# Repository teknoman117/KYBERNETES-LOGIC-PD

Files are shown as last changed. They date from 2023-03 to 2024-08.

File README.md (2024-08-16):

# Kybernetes 2 Logic Power Distribution Board

Power Distribution board for Kybernetes 2. Provides current monitoring and battery protection for a 3 cell LiPo battery and provides 5V via four USB-C ports.

Current monitoring IC is the INA219B and the switching regulator board is the Pololu D15V70F5S3. A open collector output is also provided to indicate low battery voltage.

Schematic

### Assembled
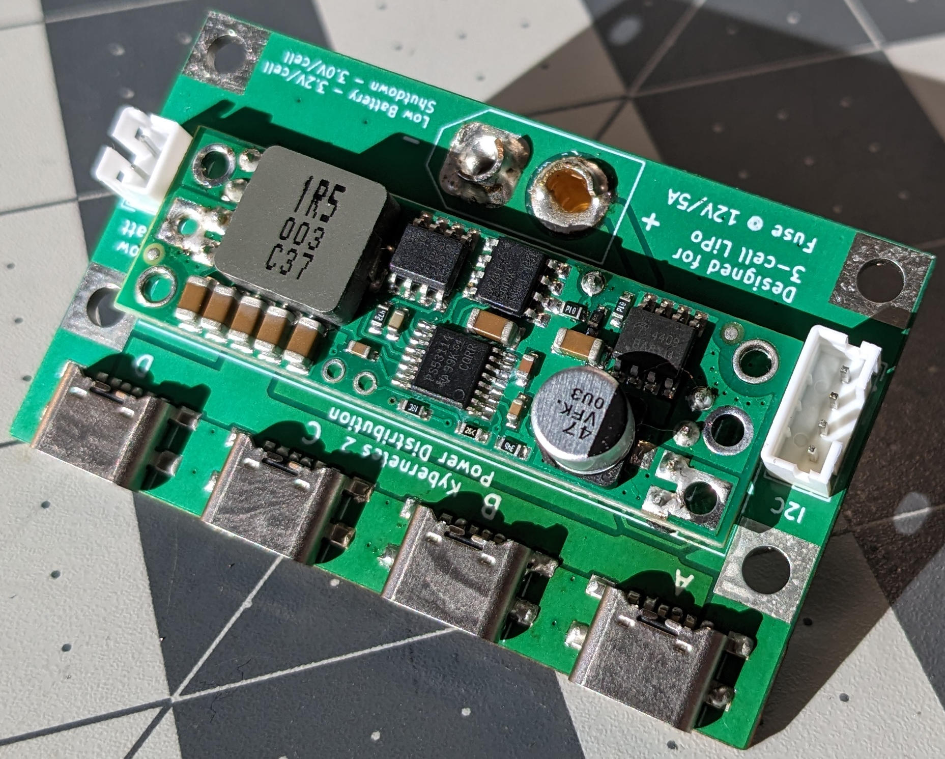
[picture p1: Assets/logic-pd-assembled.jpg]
Assembled


### Switching Regulator Removed
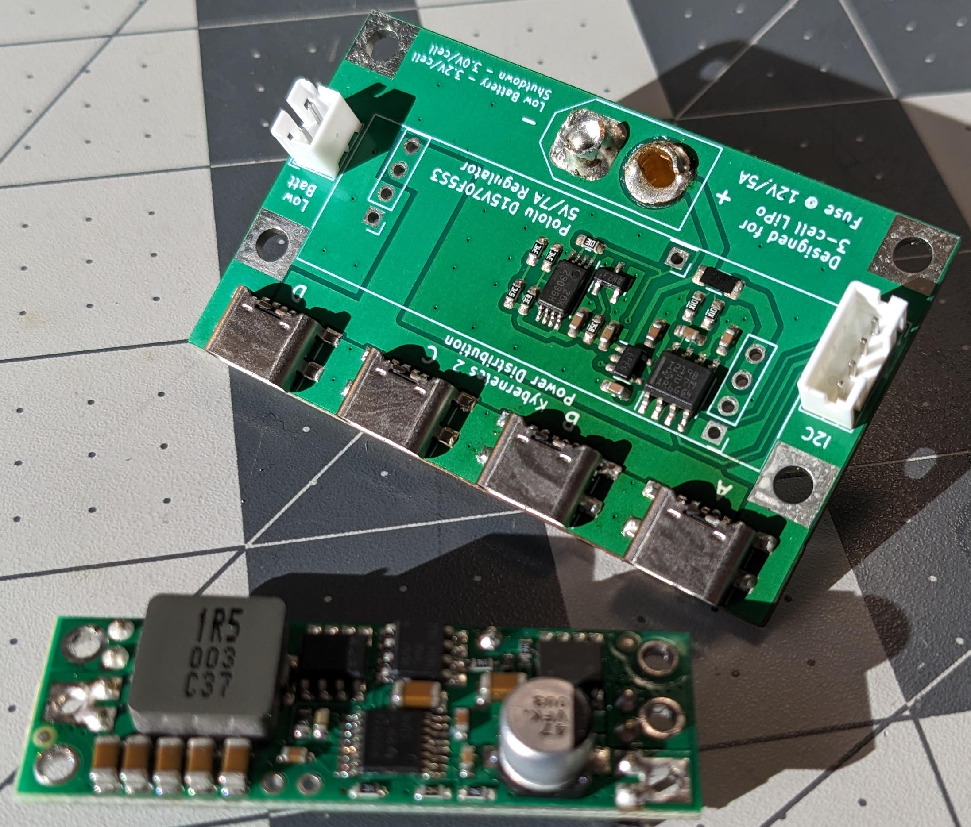
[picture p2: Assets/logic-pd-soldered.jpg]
Soldered


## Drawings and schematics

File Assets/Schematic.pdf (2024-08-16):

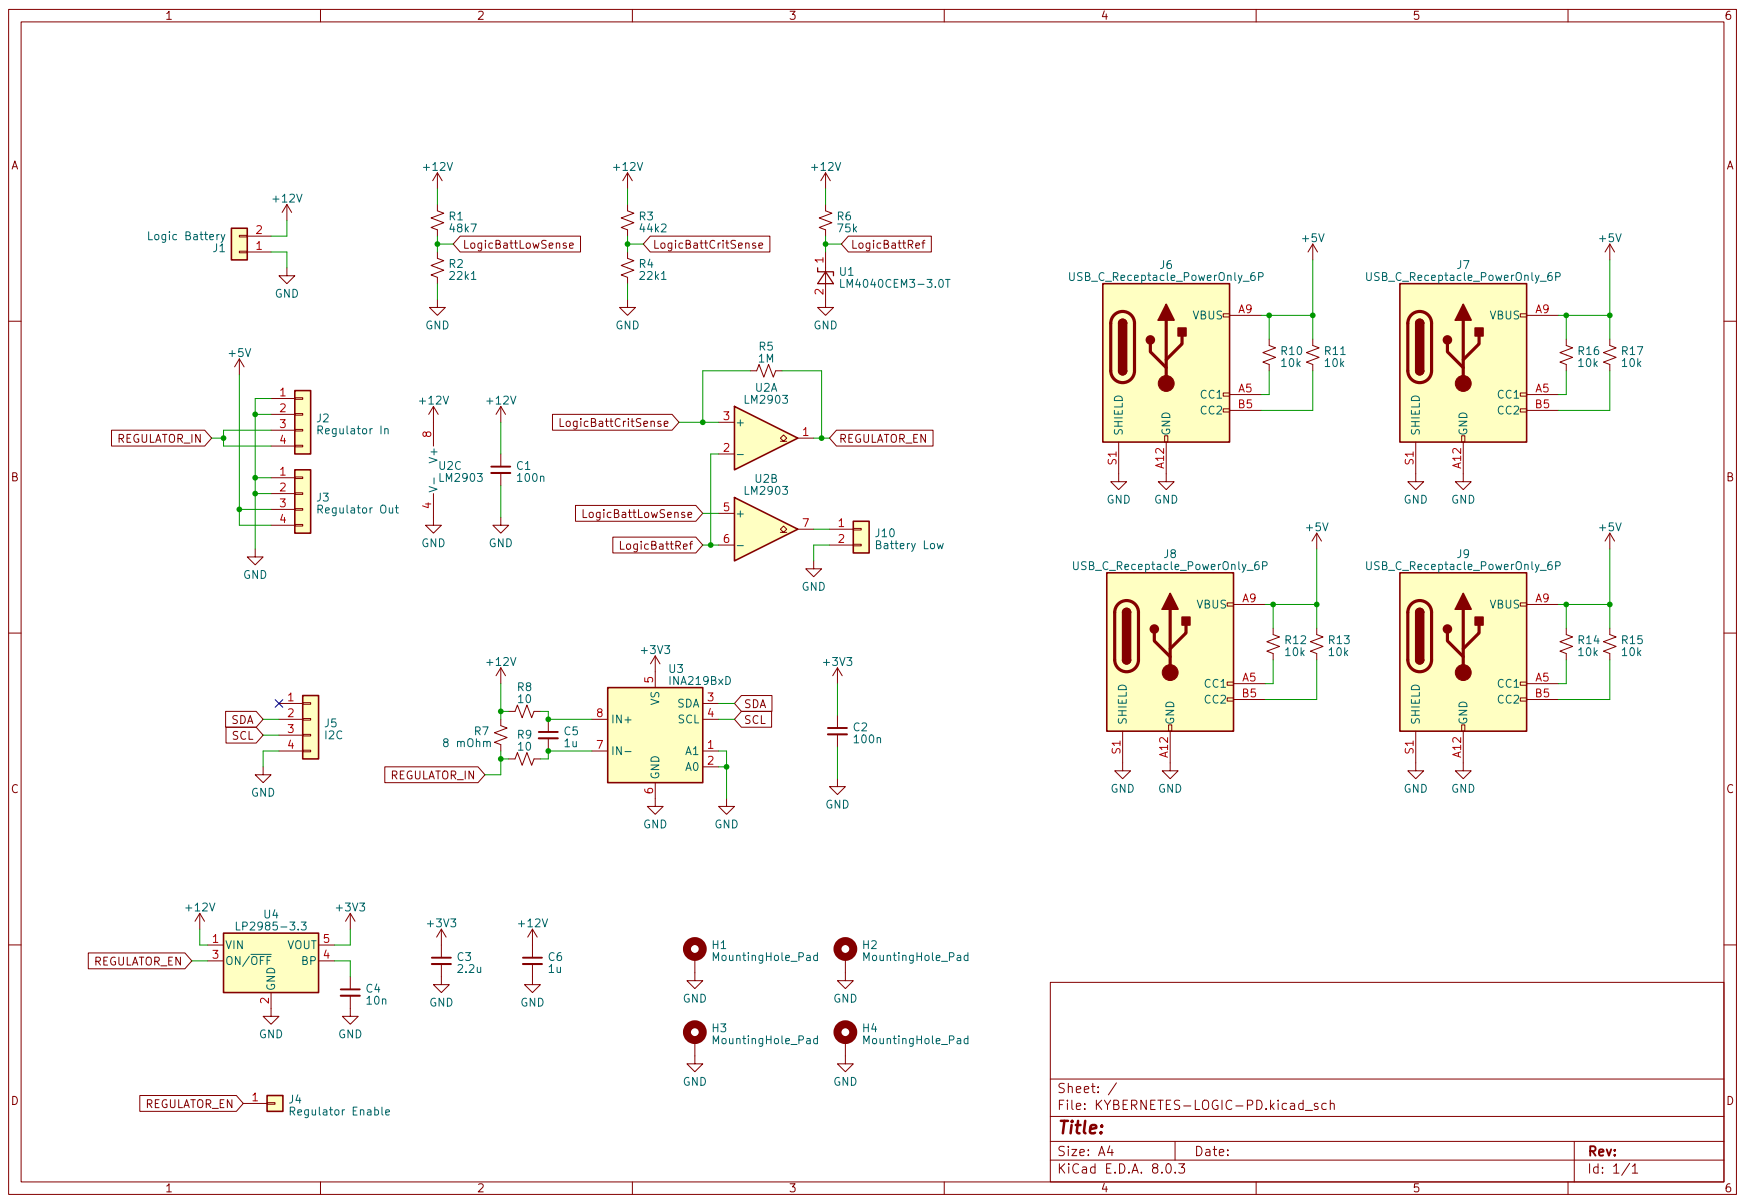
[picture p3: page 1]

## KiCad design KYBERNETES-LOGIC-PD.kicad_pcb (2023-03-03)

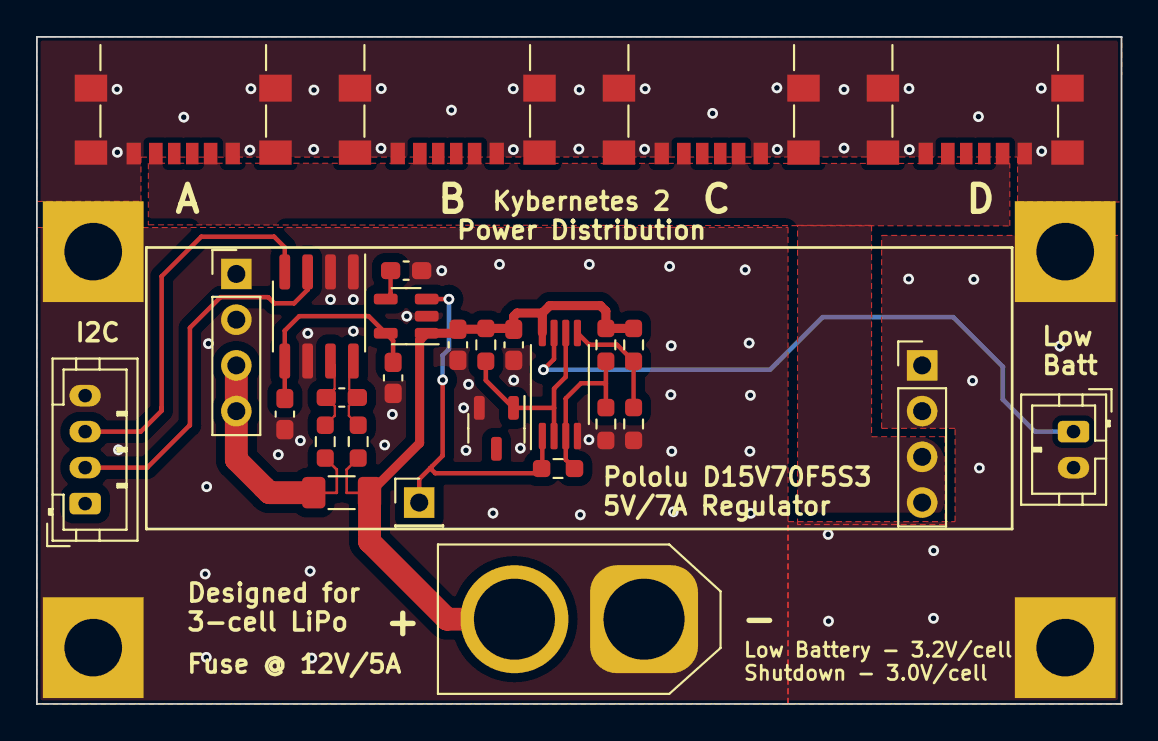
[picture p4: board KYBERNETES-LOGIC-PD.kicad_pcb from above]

Board: 2 copper layers, 60.3 x 37.1 mm, 33 parts (0 on the bottom side), 15 nets.

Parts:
C1, C2: 100n; C_0603_1608Metric_Pad1.08x0.95mm_HandSolder
C3: 2.2u; C_0603_1608Metric_Pad1.08x0.95mm_HandSolder
C4: 10n; C_0603_1608Metric_Pad1.08x0.95mm_HandSolder
C5, C6: 1u; C_0603_1608Metric_Pad1.08x0.95mm_HandSolder
H1, H2, H3, H4: MountingHole_Pad; MountingHole_3.2mm_M3_Pad_Square
J1: Logic Battery; AMASS_XT60-M_1x02_P7.20mm_Vertical
J2: Regulator In; PinHeader_1x04_P2.54mm_Vertical
J3: Regulator Out; PinHeader_1x04_P2.54mm_Vertical
J4: Regulator Enable; PinHeader_1x01_P2.54mm_Vertical
J5: I2C; JST_PH_B4B-PH-K_1x04_P2.00mm_Vertical
J6, J7, J8, J9: USB_C_Receptacle_PowerOnly_6P; USB_C_Receptacle_GCT_USB4135-GF-A_6P_TopMnt_Horizontal
J10: Battery Low; JST_PH_B2B-PH-K_1x02_P2.00mm_Vertical
R1: 48k7; R_0603_1608Metric_Pad0.98x0.95mm_HandSolder
R2, R4: 22k1; R_0603_1608Metric_Pad0.98x0.95mm_HandSolder
R3: 44k2; R_0603_1608Metric_Pad0.98x0.95mm_HandSolder
R5: 1M; R_0603_1608Metric_Pad0.98x0.95mm_HandSolder
R6: 75k; R_0603_1608Metric_Pad0.98x0.95mm_HandSolder
R7: 8 mOhm; R_1206_3216Metric_Pad1.30x1.75mm_HandSolder
R8, R9: 10; R_0603_1608Metric_Pad0.98x0.95mm_HandSolder
U1: LM4040CEM3-3.0T; SOT-23-3
U2: LM2903; TSSOP-8_4.4x3mm_P0.65mm
U3: INA219BxD; SOIC-8_3.9x4.9mm_P1.27mm
U4: LP2985-3.3; SOT-23-5

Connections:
+3V3: C2.1, C3.1, U3.5 (VS), U4.5 (VOUT)
+5V: J3.3, J3.4, J6.A9 (VBUS), J6.B9 (VBUS), J7.A9 (VBUS), J7.B9 (VBUS), J8.A9 (VBUS), J8.B9 (VBUS), J9.A9 (VBUS), J9.B9 (VBUS)
+12V: C1.1, C6.1, J1.2, R1.1, R3.1, R6.1, R7.1, R8.1, U2.8 (V+), U4.1 (VIN)
GND: C1.2, C2.2, C3.2, C4.2, C6.2, H1.1, H2.1, H3.1, H4.1, J1.1, J2.1, J2.2, J3.1, J3.2, J5.4, J6.A12 (GND), J6.B12 (GND), J6.S1 (SHIELD), J7.A12 (GND), J7.B12 (GND), J7.S1 (SHIELD), J8.A12 (GND), J8.B12 (GND), J8.S1 (SHIELD), J9.A12 (GND), J9.B12 (GND), J9.S1 (SHIELD), J10.2, R2.2, R4.2, U1.2 (A), U2.4 (V-), U3.1 (A1), U3.2 (A0), U3.6 (GND), U4.2 (GND)
LogicBattCritSense: R3.2, R4.1, R5.1, U2.3 (+)
LogicBattLowSense: R1.2, R2.1, U2.5 (+)
LogicBattRef: R6.2, U1.1 (K), U2.2 (-), U2.6 (-)
unnamed: J10.1, U2.7
unnamed: C5.1, R8.2, U3.8 (IN+)
unnamed: C5.2, R9.2, U3.7 (IN-)
unnamed: C4.1, U4.4 (BP)
REGULATOR_EN: J4.1, R5.2, U2.1, U4.3 (ON/~OFF)
REGULATOR_IN: J2.3, J2.4, R7.2, R9.1
SCL: J5.3, U3.4 (SCL)
SDA: J5.2, U3.3 (SDA)

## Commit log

2023-03-02 further work
    [KYBERNETES-LOGIC-PD.kicad_pcb, KYBERNETES-LOGIC-PD.kicad_sch]
2023-03-02 more work
    [KYBERNETES-LOGIC-PD.kicad_pcb]
2023-03-02 first version for manufacturing
    [KYBERNETES-LOGIC-PD-B_Cu.gbl, KYBERNETES-LOGIC-PD-B_Mask.gbs, KYBERNETES-LOGIC-PD-B_Paste.gbp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]
2023-03-03 source needs 10 Kohm pullups to advertise 3A capability
    [KYBERNETES-LOGIC-PD.kicad_pcb, KYBERNETES-LOGIC-PD.kicad_sch]
2024-08-16 add schematic rendering
